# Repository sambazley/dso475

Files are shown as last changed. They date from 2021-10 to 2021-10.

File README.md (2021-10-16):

# USB Interface for Gould 475 Oscilloscope

PCB and software to interface a Gould 475 oscilloscope with a PC over USB.

The STM32 software interprets the HPGL that is output from the oscilloscope and
converts it to SVG format. The SVG data is transmitted to dsoctl over USB.

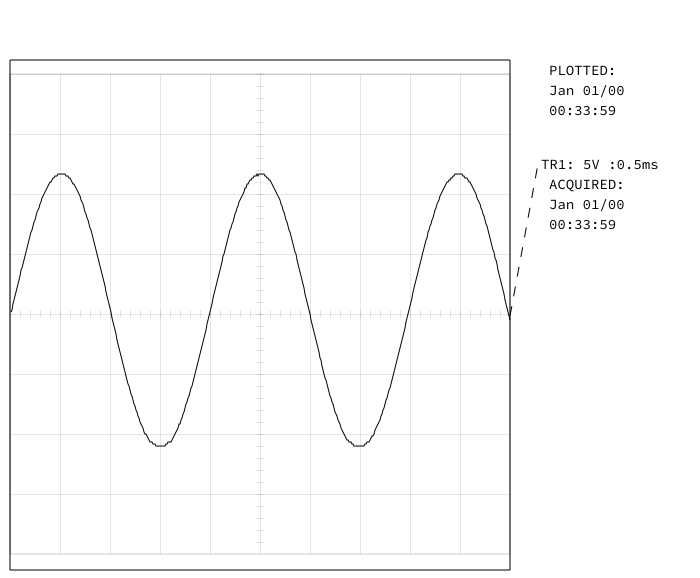
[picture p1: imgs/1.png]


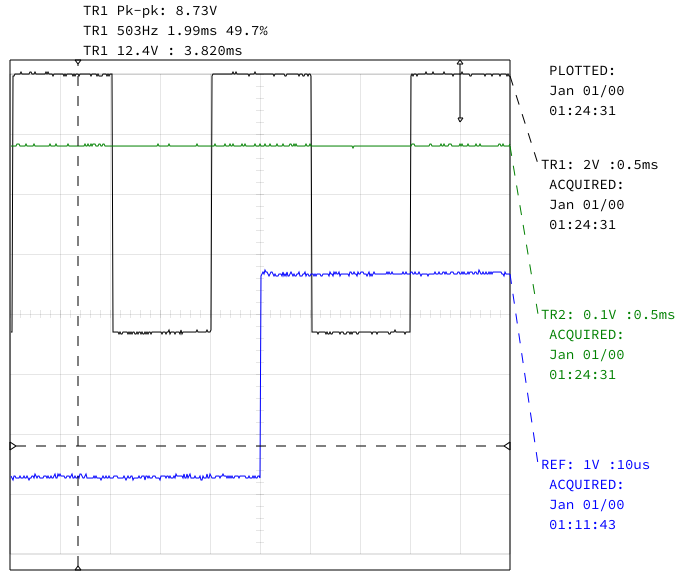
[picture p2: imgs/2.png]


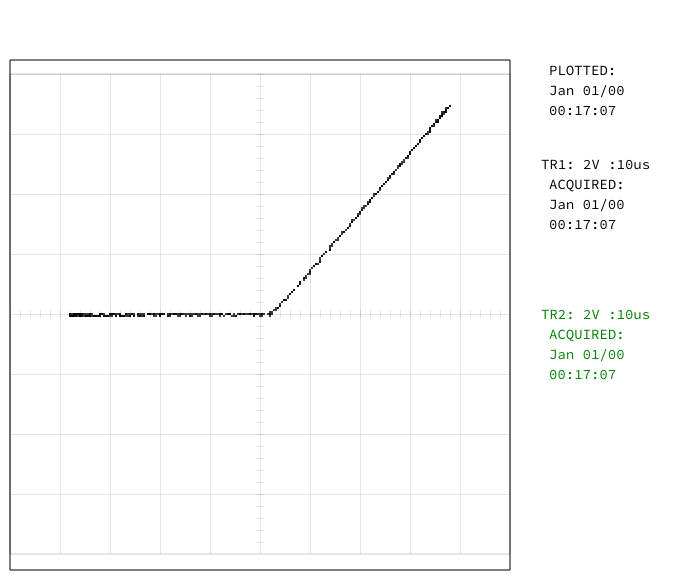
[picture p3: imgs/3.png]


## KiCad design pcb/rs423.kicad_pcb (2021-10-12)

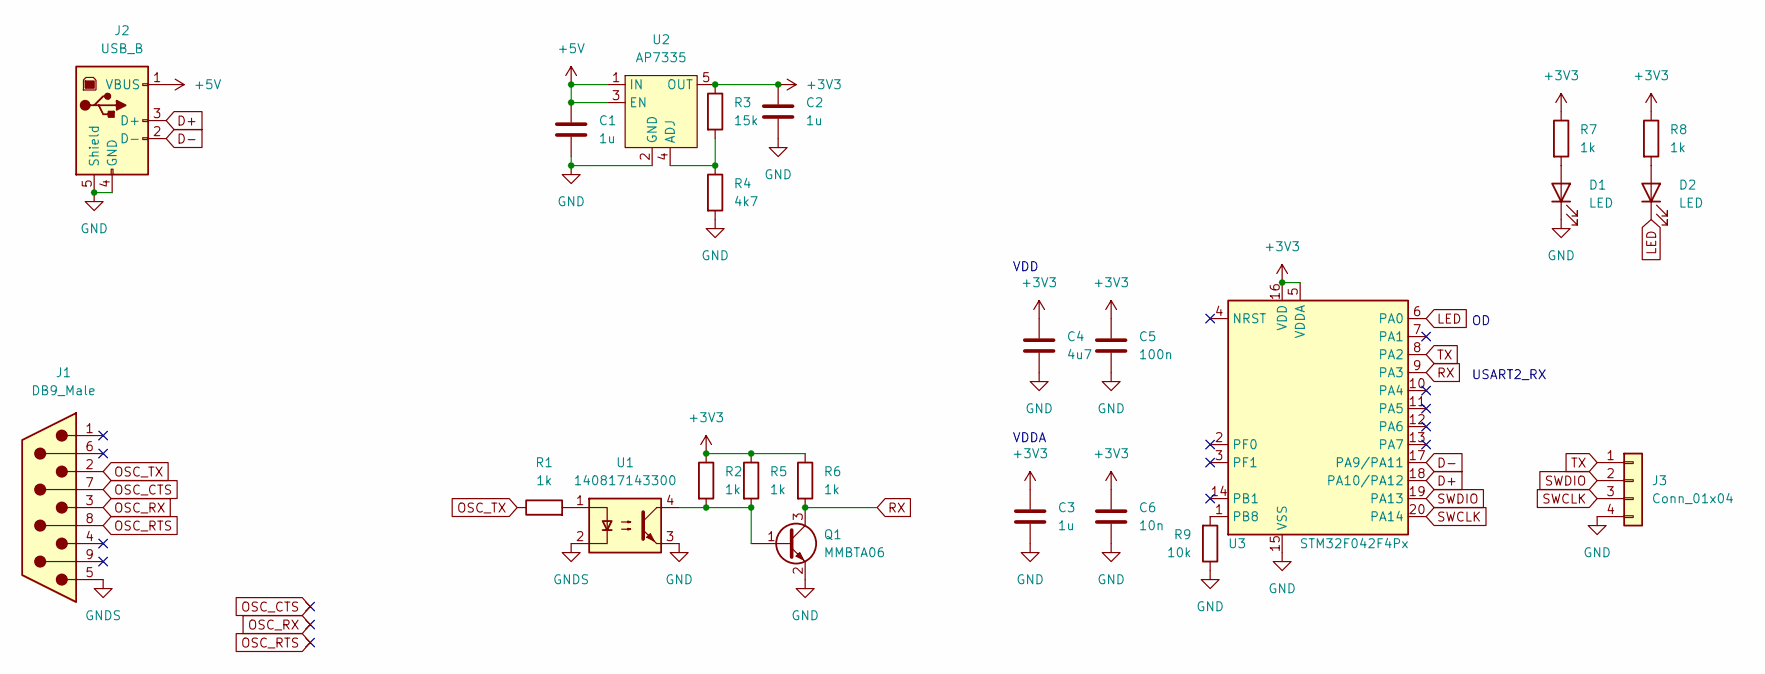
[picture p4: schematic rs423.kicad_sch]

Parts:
C1, C2, C3: 1u; C_0805_2012Metric
C4: 4u7; C_0805_2012Metric
C5: 100n; C_0805_2012Metric
C6: 10n; C_0805_2012Metric
D1, D2: LED; LED_0805_2012Metric
J1: DB9_Male; A-DS 09 A_KG-T4S
J2: USB_B; UJ2-BH-TH
J3: Conn_01x04; PinHeader_1x04_P2.54mm_Vertical
Q1: MMBTA06; SOT-23
R1, R2, R5, R6, R7, R8: 1k; R_0805_2012Metric
R3: 15k; R_0805_2012Metric
R4: 4k7; R_0805_2012Metric
R9: 10k; R_0805_2012Metric
U1: 140817143300; SMDIP-4_W9.53mm
U2: AP7335; SOT-23-5
U3: STM32F042F4Px; TSSOP-20_4.4x6.5mm_P0.65mm

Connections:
+3V3: C2.1, C3.1, C4.1, C5.1, C6.1, R2.1, R3.1, R5.1, R6.1, R7.1, R8.1, U2.5 (OUT), U3.5 (VDDA), U3.16 (VDD)
+5V: C1.1, J2.1 (VBUS), U2.1 (IN), U2.3 (EN)
D+: J2.3 (D+), U3.18 (PA10/PA12)
D-: J2.2 (D-), U3.17 (PA9/PA11)
GND: C1.2, C2.2, C3.2, C4.2, C5.2, C6.2, D1.1 (K), J2.4 (GND), J2.5 (Shield), J3.4, Q1.2 (E), R4.2, R9.1, U1.3, U2.2 (GND), U3.15 (VSS)
GNDS: J1.5, U1.2
LED: D2.1 (K), U3.6 (PA0)
unnamed: D1.2 (A), R7.2
unnamed: D2.2 (A), R8.2
unnamed: Q1.1 (B), R2.2, R5.2, U1.4
unnamed: R1.2, U1.1
unnamed: R3.2, R4.1, U2.4 (ADJ)
unnamed: R9.2, U3.1 (PB8)
OSC_CTS: J1.7
OSC_RTS: J1.8
OSC_RX: J1.3
OSC_TX: J1.2, R1.1
RX: Q1.3 (C), R6.2, U3.9 (PA3)
SWCLK: J3.3, U3.20 (PA14)
SWDIO: J3.2, U3.19 (PA13)
TX: J3.1, U3.8 (PA2)

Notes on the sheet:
VDD
VDDA
USART2_RX

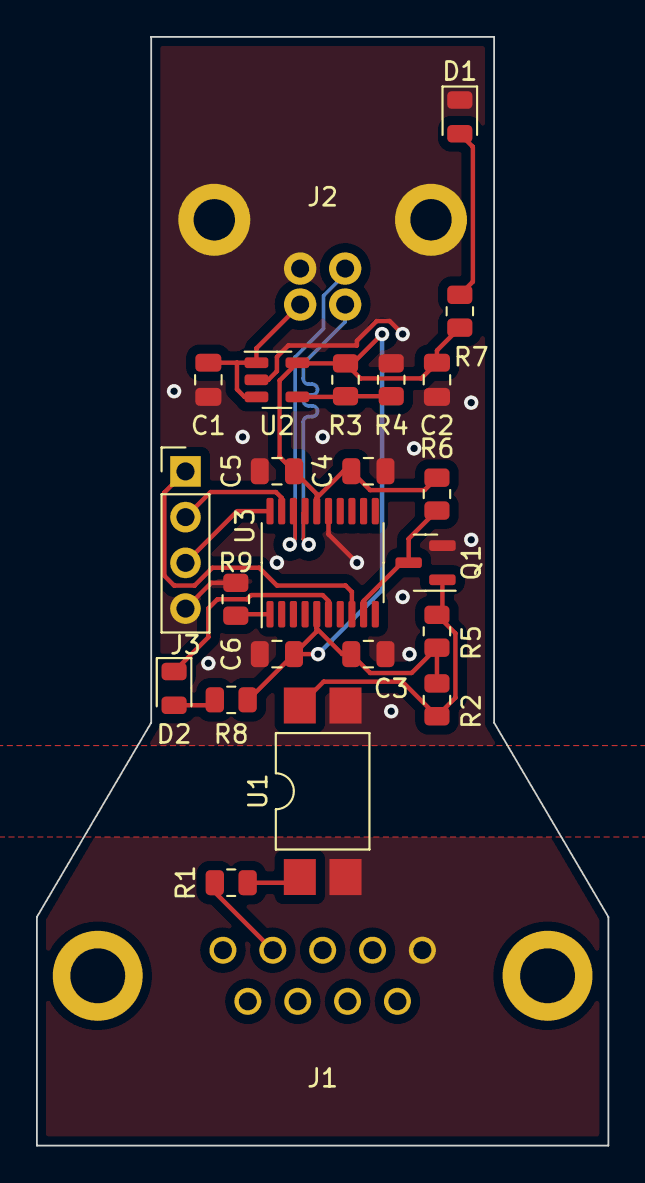
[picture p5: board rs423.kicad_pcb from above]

Board: 2 copper layers, 31.8 x 61.6 mm, 24 parts (0 on the bottom side), 18 nets.

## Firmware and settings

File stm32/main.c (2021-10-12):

/* Copyright (C) 2021 Sam Bazley
 *
 * This software is provided 'as-is', without any express or implied
 * warranty.  In no event will the authors be held liable for any damages
 * arising from the use of this software.
 *
 * Permission is granted to anyone to use this software for any purpose,
 * including commercial applications, and to alter it and redistribute it
 * freely, subject to the following restrictions:
 *
 * 1. The origin of this software must not be misrepresented; you must not
 *    claim that you wrote the original software. If you use this software
 *    in a product, an acknowledgment in the product documentation would be
 *    appreciated but is not required.
 * 2. Altered source versions must be plainly marked as such, and must not be
 *    misrepresented as being the original software.
 * 3. This notice may not be removed or altered from any source distribution.
 */

#include "hpgl.h"
#include "uart.h"
#include "usb.h"
#include <usblib.h>
#include <stm32f0xx.h>

void rcc_init()
{
	FLASH->ACR |= FLASH_ACR_LATENCY;

	RCC->CR2 |= RCC_CR2_HSI48ON;

	while (!(RCC->CR2 & RCC_CR2_HSI48RDY)) {
		__NOP();
	}

	RCC->CFGR |= RCC_CFGR_SW_HSI48;

	while (!(RCC->CFGR & RCC_CFGR_SWS_HSI48)) {
		__NOP();
	}
}

void boot()
{
	rcc_init();
	uart_init();

	RCC->AHBENR |= RCC_AHBENR_GPIOAEN;
	GPIOA->MODER &= ~(3 << (2 * 0));
	GPIOA->MODER |= 1 << (2 * 0);
	GPIOA->OTYPER |= 1 << 0;
	GPIOA->ODR |= 1;

	usb_impl_init();

	while (1) {
		if (usb_get_selected_config() != 0) {
			break;
		}
	}

	uart_send_str("booted\n");

	hpgl_loop();
}

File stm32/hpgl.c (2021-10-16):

/* Copyright (C) 2021 Sam Bazley
 *
 * This software is provided 'as-is', without any express or implied
 * warranty.  In no event will the authors be held liable for any damages
 * arising from the use of this software.
 *
 * Permission is granted to anyone to use this software for any purpose,
 * including commercial applications, and to alter it and redistribute it
 * freely, subject to the following restrictions:
 *
 * 1. The origin of this software must not be misrepresented; you must not
 *    claim that you wrote the original software. If you use this software
 *    in a product, an acknowledgment in the product documentation would be
 *    appreciated but is not required.
 * 2. Altered source versions must be plainly marked as such, and must not be
 *    misrepresented as being the original software.
 * 3. This notice may not be removed or altered from any source distribution.
 */

#include "hpgl.h"
#include "usb.h"
#include <stdlib.h>
#include <string.h>
#include <stm32f0xx.h>
#include "uart.h"

static const char *header = "\
<?xml version=\"1.0\" encoding=\"UTF-8\" standalone=\"no\"?>\n\
<!DOCTYPE svg PUBLIC \"-//W3C//DTD SVG 1.1//EN\" \"http://www.w3.org/Graphics/SVG/1.1/DTD/svg11.dtd\">\n\
<svg width=\"700\" height=\"578\" viewBox=\"-10 -10 700 578\" xmlns=\"http://www.w3.org/2000/svg\" xmlns:xlink=\"http://www.w3.org/1999/xlink\">\n";

static const char *graticule = "\
<defs>\n\
<pattern id=\"grid\" width=\"50\" height=\"60\" y=\"64\" patternUnits=\"userSpaceOnUse\">\n\
<path d=\"M 50 0 L 0 0 0 60\" fill=\"none\" stroke=\"black\" stroke-width=\"0.2\"/>\n\
</pattern>\n\
<pattern id=\"xaxis\" width=\"10\" height=\"8\" patternUnits=\"userSpaceOnUse\">\n\
<path d=\"M 0 0 L 0 8\" fill=\"none\" stroke=\"black\" stroke-width=\"0.2\"/>\n\
</pattern>\n\
<pattern id=\"yaxis\" width=\"8\" height=\"12\" y=\"64\" patternUnits=\"userSpaceOnUse\">\n\
<path d=\"M 0 0 L 8 0\" fill=\"none\" stroke=\"black\" stroke-width=\"0.2\"/>\n\
</pattern>\n\
</defs>\n\
<rect width=\"500\" height=\"480\" y=\"64\" fill=\"none\" stroke=\"black\" stroke-width=\"0.2\" />\n\
<rect width=\"500\" height=\"480\" y=\"64\" fill=\"url(#grid)\" />\n\
<rect y=\"300\" width=\"500\" height=\"8\" fill=\"url(#xaxis)\" />\n\
<rect x=\"246\" y=\"64\" width=\"8\" height=\"480\" fill=\"url(#yaxis)\" />\n";

static char buf [128], *buf_ptr = buf;

static int pen = 0;
static int pen_down = 0;
static int line_type = 0;
static int x = 0;
static int y = 256;
static int xy_state = 0;

static void sp()
{
	if (buf_ptr - buf <= 1 || (buf_ptr[-1] != ',' && buf_ptr[-1] != ';')) {
		return;
	}

	int new_pen = *buf - '0';

	if (pen == 0 && new_pen != 0) {
		usb_log_str(header);
		usb_log_str(graticule);
	} else if (pen != 0 && new_pen == 0) {
		usb_log_str("</svg>\n");
	}

	pen = new_pen;

	buf_ptr = buf;
}

static void color()
{
	switch (pen) {
	case 2:
		usb_log_str("green");
		break;
	case 3:
		usb_log_str("blue");
		break;
	default:
		usb_log_str("black");
	}
}


static void line_start()
{
	usb_log_str("<polyline stroke=\"");

	color();

	usb_log_str("\" ");

	switch (line_type) {
	case 2:
		usb_log_str("stroke-dasharray=\"10 10\" ");
		break;
	}

	usb_log_str("points=\"");
}

static void line_end()
{
	usb_log_str("\" stroke-width=\"1\" fill=\"none\" />\n");
}

#define MIN(a, b) ((a) < (b) ? (a) : (b))
#define MAX(a, b) ((a) > (b) ? (a) : (b))
#define CLAMP(x, a, b) (MIN(MAX(x, a), b))
#define Y(y) CLAMP((560 - (y) * 2), 0, 560)

static void pr_start()
{
	if (!pen_down) {
		return;
	}

	line_start();

	buf_ptr = buf;
}

static void pr()
{
	if (buf_ptr - buf <= 1 || (buf_ptr[-1] != ',' && buf_ptr[-1] != ';')) {
		return;
	}

	buf_ptr[-1] = 0;
	buf_ptr = buf;

	int n = atoi(buf);

	xy_state ^= 1;

	if (xy_state == 1) {
		x += n;
		return;
	}

	y += n;
	usb_log_int(x);
	usb_log_str(",");
	usb_log_int(Y(y));
	usb_log_str(" ");
}

static void pr_end()
{
	if (!pen_down) {
		return;
	}

	line_end();
}

static void pa()
{
	if (!pen_down) {
		return;
	}

	if (buf_ptr - buf <= 1 || (buf_ptr[-1] != ',' && buf_ptr[-1] != ';')) {
		return;
	}

	buf_ptr[-1] = 0;
	buf_ptr = buf;

	int n = atoi(buf);

	xy_state ^= 1;

	if (xy_state == 1) {
		x = n;
		return;
	}

	y = n;

	usb_log_str("<circle cx=\"");
	usb_log_int(x);
	usb_log_str("\" cy=\"");
	usb_log_int(Y(y));
	usb_log_str("\" r=\"1\" fill=\"black\" />\n");
}

static void pd_start()
{
	pen_down = 1;

	buf_ptr = buf;
}

static void pd()
{
	if (!pen_down) {
		return;
	}

	if (buf_ptr - buf <= 1 || (buf_ptr[-1] != ',' && buf_ptr[-1] != ';')) {
		return;
	}

	buf_ptr[-1] = 0;
	buf_ptr = buf;

	int n = atoi(buf);

	xy_state ^= 1;

	static int old_x, old_y;

	if (xy_state) {
		old_x = x;
		x = n;
	} else {
		old_y = y;
		y = n;

		line_start();
		usb_log_int(old_x);
		usb_log_str(",");
		usb_log_int(Y(old_y));
		usb_log_str(" ");
		usb_log_int(x);
		usb_log_str(",");
		usb_log_int(Y(y));
		line_end();
	}
}

static void pu()
{
	if (buf_ptr - buf <= 1 || (buf_ptr[-1] != ',' && buf_ptr[-1] != ';')) {
		return;
	}

	buf_ptr[-1] = 0;
	buf_ptr = buf;

	int n = atoi(buf);

	xy_state ^= 1;

	if (xy_state) {
		x = n;
	} else {
		y = n;
	}

	pen_down = 0;
}

static void lb()
{
	if (buf_ptr[-1] == 0x03) {
		return;
	}

	char str [] = {buf_ptr[-1], 0};
	usb_log_str(str);

	buf_ptr = buf;
}

static void lb_start()
{
	usb_log_str("<text x=\"");
	usb_log_int(x + 3);
	usb_log_str("\" y=\"");
	usb_log_int(Y(y) + 5);
	usb_log_str("\" font-family=\"mono\" font-size=\"14\" fill=\"");
	color();
	usb_log_str("\">");
}

static void lb_end()
{
	usb_log_str("</text>\n");
}

static void lt()
{
	if (buf_ptr - buf <= 1 || buf_ptr[-1] != ';') {
		line_type = 0;
		return;
	}

	line_type = atoi(buf);
}

static struct cmd {
	const char *str;
	void (*func)();
	void (*start)();
	void (*end)();
} cmds [] = {
	{"SP", sp, 0, 0},
	{"PR", pr, pr_start, pr_end},
	{"PA", pa, 0, 0},
	{"PD", pd, pd_start, 0},
	{"PU", pu, 0, 0},
	{"LB", lb, lb_start, lb_end},
	{"LT", lt, 0, 0}
};

static struct cmd *cmd = 0;

static volatile int overflow = 0;

static volatile char uart_buf [128];
static volatile uint16_t uart_buf_len = 0;

void hpgl_received(char c)
{
	if (uart_buf_len >= sizeof(uart_buf)) {
		overflow = 1;
		return;
	}

	uart_buf[uart_buf_len++] = c;
}
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

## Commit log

2021-10-12 Add PCB files
    [rs423.kicad_pcb, rs423.kicad_sch]
2021-10-12 Add STM32 code
    [flash.cfg]
